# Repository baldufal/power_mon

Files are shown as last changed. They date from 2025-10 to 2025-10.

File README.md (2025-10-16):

# PowerMon
A **9-channel power monitoring and control board** based on the [INA3221](https://www.ti.com/product/INA3221) current sensor and an [ESP32-C3 super mini](https://www.espboards.dev/esp32/esp32-c3-super-mini/) running (a custom compiled version of) [Tasmota](https://tasmota.github.io/).

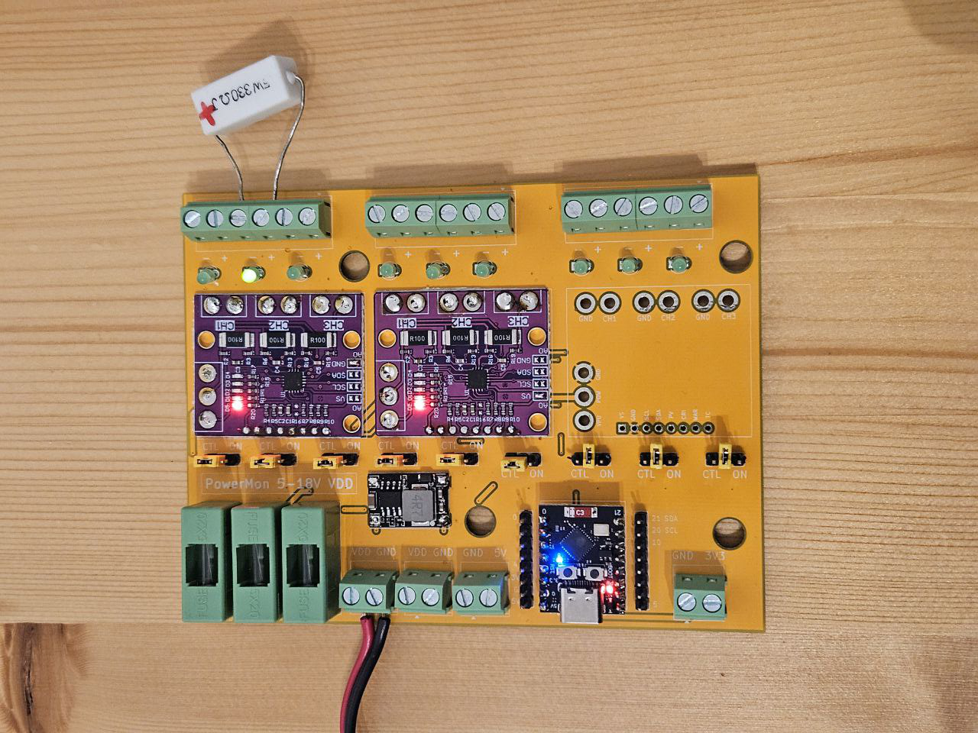
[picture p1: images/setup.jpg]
assembled board

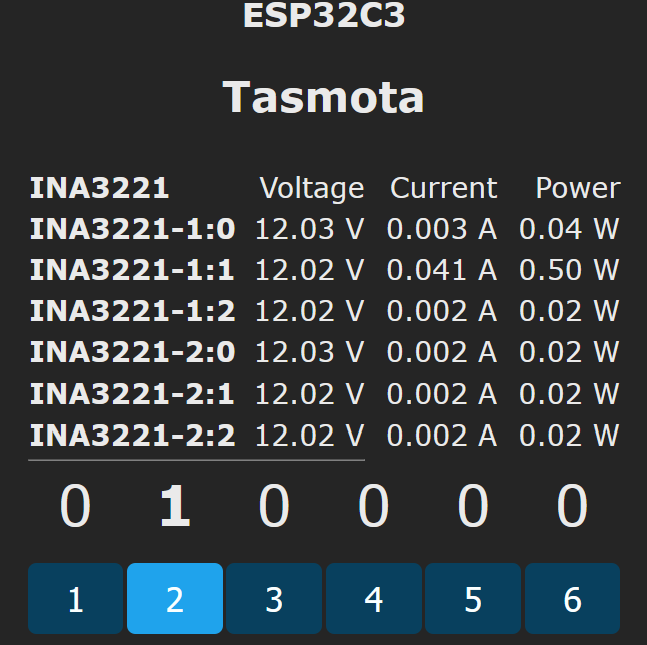
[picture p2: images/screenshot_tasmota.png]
tasmota ui


## Features
- 9 individually controllable output channels
- Each channel can be permanently enabled/disabled using jumpers
- LEDs indicating the output state of each channel
- Power sensing for each individual channel
- -5 ~ 28V output voltage (shared between all outputs)
- 3 integrated fuse holders (5x20mm)

## Board
The board was designed using KiCad 9.
It uses custom symbols and footprints which can be found in the [footprints](footprints) directory.

Care should be taken that the right versions of the ESP32-C3 Super Mini and the INA3221 are selected (see below).
The voltage is regulated using a compact 5V volatage regulator module.

[Schematics](images/schematics_overview.png)
[Schematics for outputs](images/schematics_outputs.png)
[PCB](images/pcb.png)

The board was fabricated by [JLCPCB](https://jlcpcb.com/) and soldered by hand.

### BOM
| Qty | Part |
| --- | --- |
| 1 | **ESP32-C3 Super Mini** (there are [two versions](https://roryhay.es/blog/esp32-c3-super-mini-flaw)) |
| 3 | **INA3221 module** (the [_old version_](https://youtu.be/tCXCQwTQt9Q?si=c6mN08hn90Hn1HyM) with shared GND) |
| 1 | 5V voltage regulator [module](https://de.aliexpress.com/item/1005008257960729.html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) |
| 3 | 5x20mm fuse holder |
| 9 | SOT23 n-Channel FET like [SI2302](https://www.vishay.com/docs/68645/si2302cds.pdf) / A2SHB |
| 9 | 3mm LED with resistors |
| 9 | pin header with 3 poles + jumpers |
| 2 | pin header with 8 poles |
| 13 | 5.08mm terminal blocks with 2 poles |

## Tasmota compilation
As INA3221 support is not enabled in any of the precompiled Tasmota versions, a [custom compiled](https://github.com/tasmota/docs/blob/master/docs/Compile-your-build.md) Tasmota is used.

1. Download the latest version of [Tasmota](https://github.com/arendst/Tasmota) and open it in [PlatformIO](https://platformio.org/).
2. Enable I2C and INA3221 drivers in **tasmota/user_config_override.h** by inserting
```
#ifndef USE_I2C
#define USE_I2C
#endif

#ifndef USE_INA3221
#define USE_INA3221
#endif
```
3. In **platformio_override.ini** change _default_envs_ to `tasmota32c3` and _board_ to `esp32c3`.
4. Compile and upload.

## Tasmota configuration
To configure the freshly flashed Tasmota:

First, [connect it to your wifi](https://tasmota.github.io/docs/Getting-Started/#__tabbed_2_2).

Then, set a **static IP** using the console for a more stable connection ([see the docs](https://tasmota.github.io/docs/Commands/#wi-fi)):
```
ipaddress1 <host IP address>
ipaddress2 <gateway IP address>
ipaddress3 <subnet mask>
ipaddress4 <DNS 1 IP>
ipaddress5 1.1.1.1
```

Then **disable the feature that resets everything** if a `Button` is pressed for 5 seconds:
```
SetOption1 1
```

Then set the **pin configuration**:

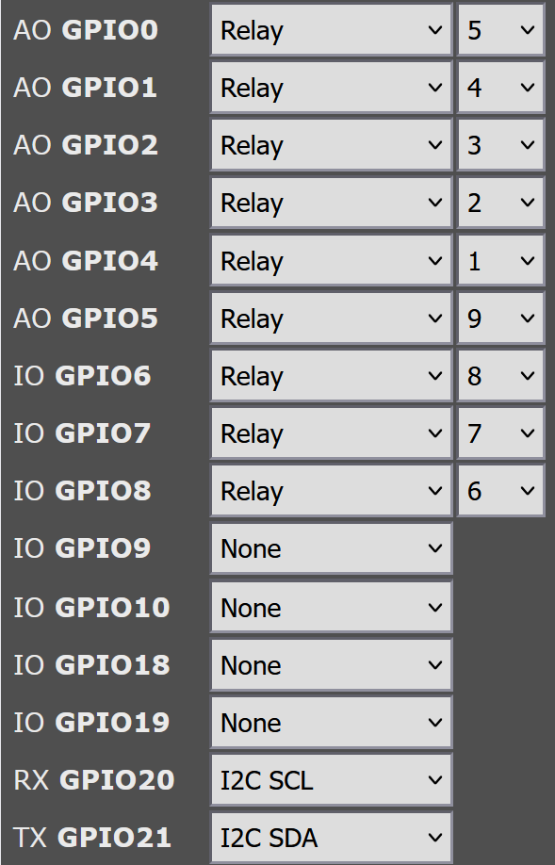
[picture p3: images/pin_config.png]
target pin config


Then create a [rule](https://tasmota.github.io/docs/Rules/) that [**configures the INA3221 sensors**](https://staars.github.io/docs/Commands/#sensors) after startup:
```
Rule1 ON System#Boot DO Sensor100 1, 0.1, 0.1, 0.1 ENDON ON System#Boot DO Sensor100 2, 0.1, 0.1, 0.1 ENDON ON System#Boot DO Sensor100 3, 0.1, 0.1, 0.1 ENDON
```
and enable it:
```
Rule1 1
```

Optionally, configure the number of decimals using
```
VoltRes 2
AmpRes 3
WattRes 2
```

## See also
[Here](https://github.com/arendst/Tasmota/discussions/16660) is a discussion of INA3221 configuration in Tasmota.

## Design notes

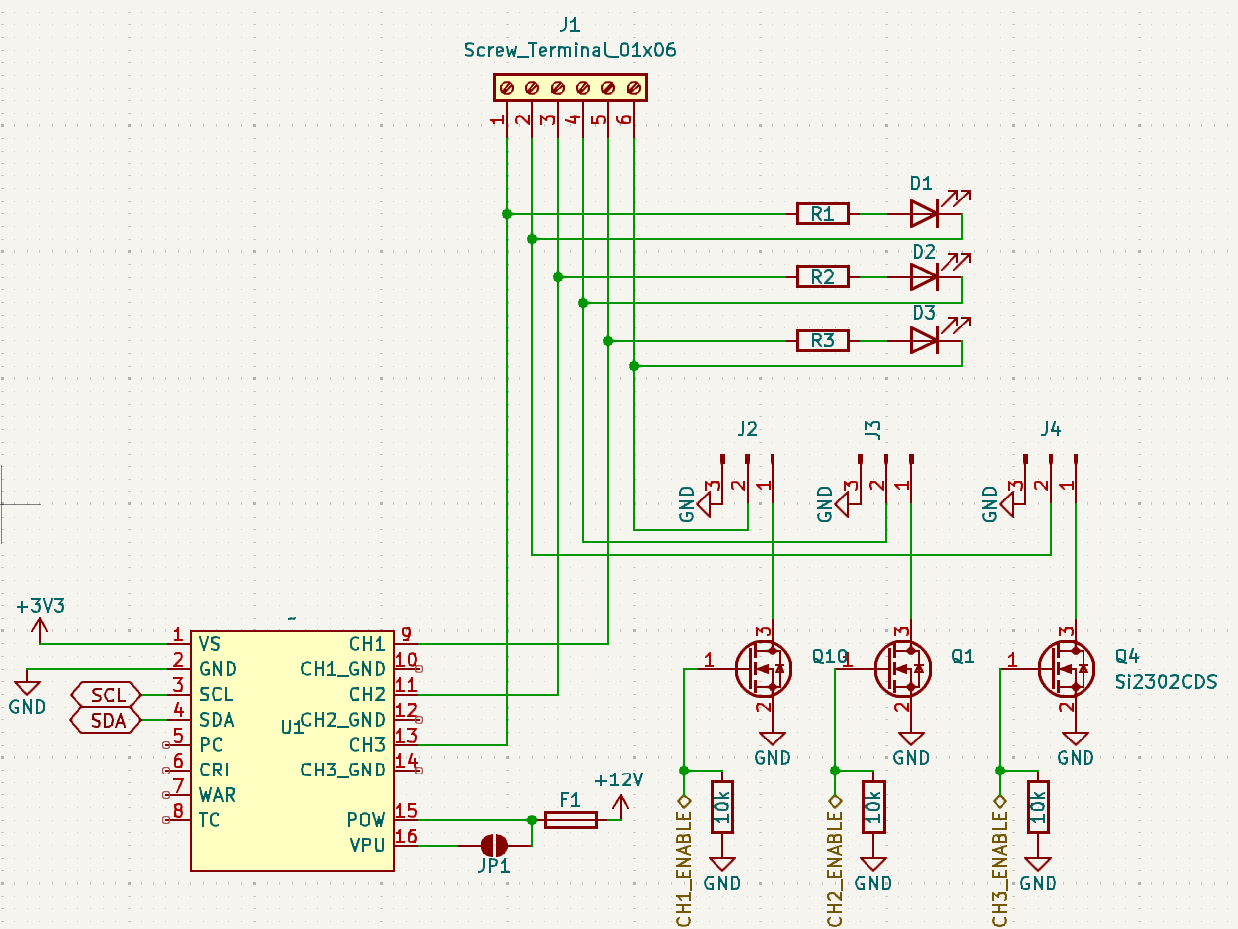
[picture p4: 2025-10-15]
images/schematics_outputs.png

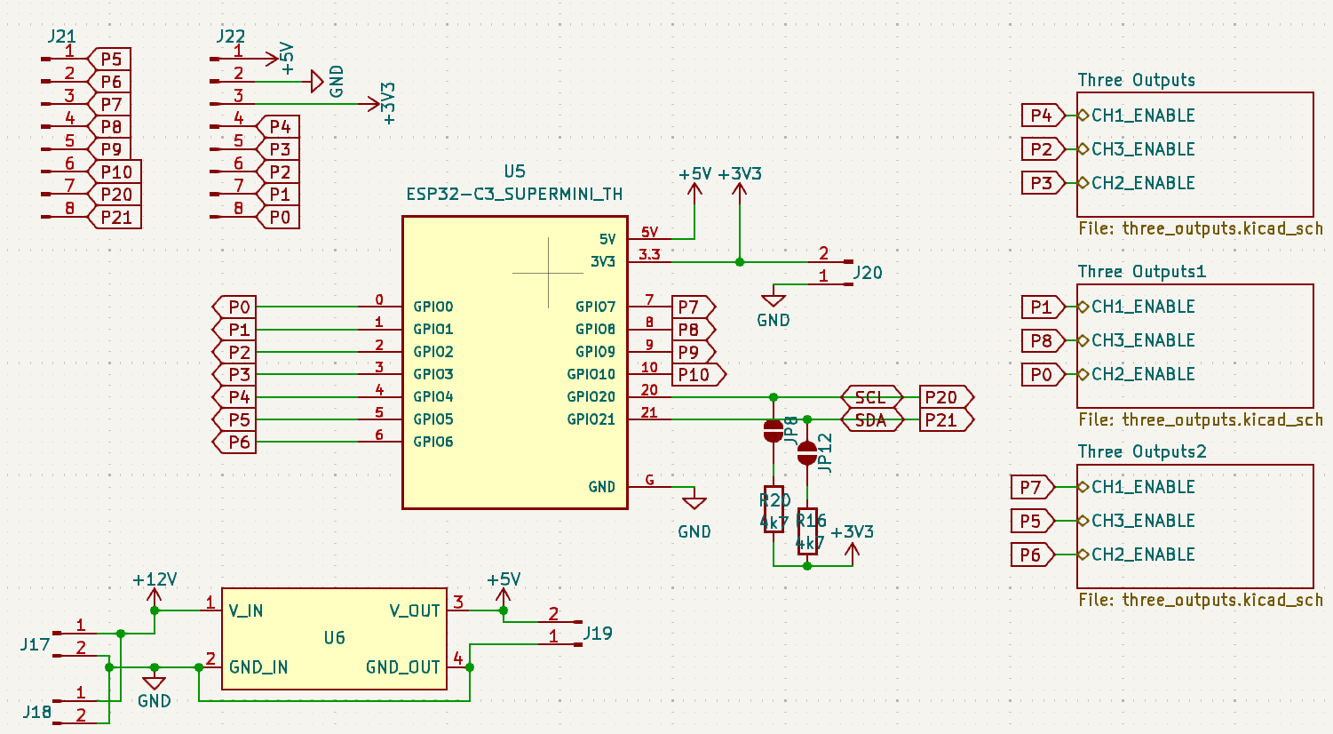
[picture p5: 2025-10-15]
images/schematics_overview.png

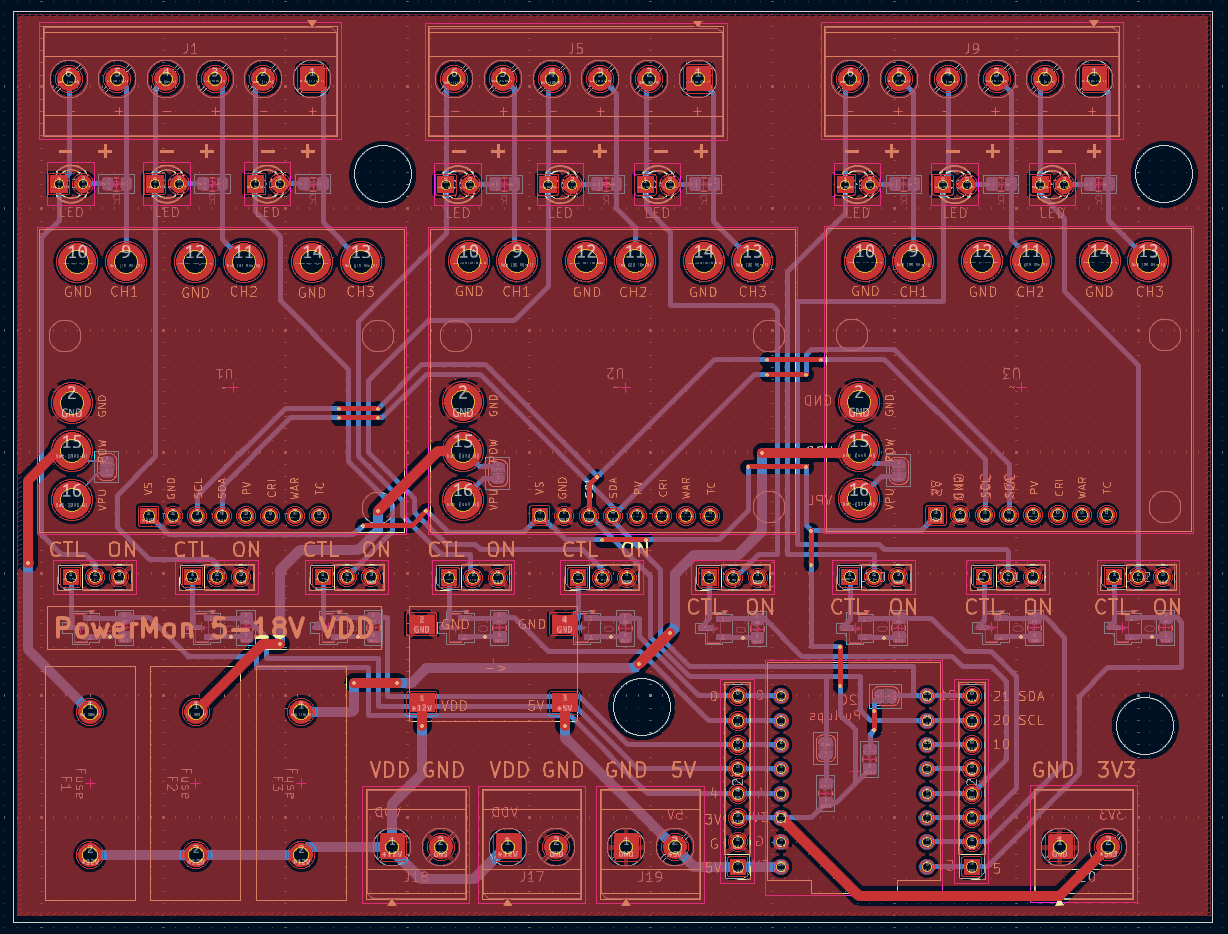
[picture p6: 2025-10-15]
images/pcb.png

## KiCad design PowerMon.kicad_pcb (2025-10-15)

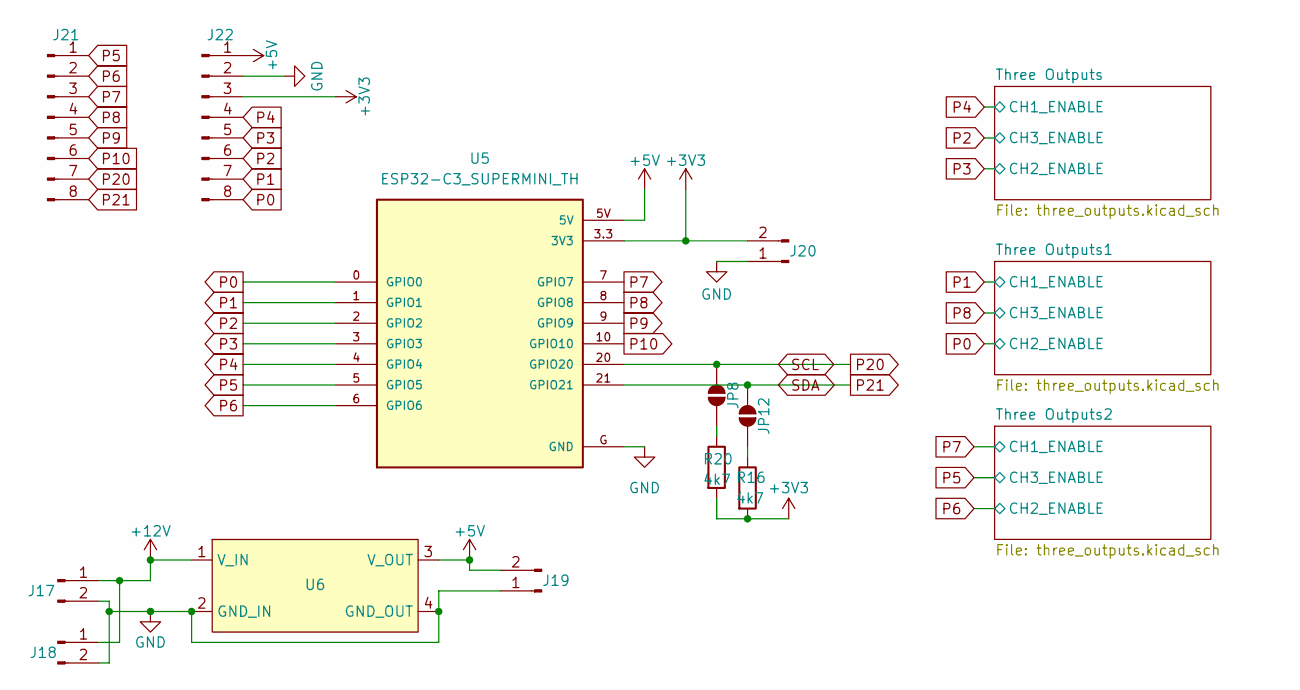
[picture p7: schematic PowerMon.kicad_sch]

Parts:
J17, J18, J19, J20: Conn_01x02_Pin; TerminalBlock_Phoenix_MKDS-3-2-5.08_1x02_P5.08mm_Horizontal
J21, J22: Conn_01x08_Pin; PinHeader_1x08_P2.54mm_Vertical
JP8, JP12: SolderJumper_2_Open; SolderJumper-2_P1.3mm_Open_RoundedPad1.0x1.5mm
R16, R20: 4k7; R_0805_2012Metric_Pad1.20x1.40mm_HandSolder
U5: ESP32-C3_SUPERMINI_TH; MODULE_ESP32-C3_SUPERMINI_TH
U6: DC_DC_3A_Mini_Aliexpress

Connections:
+3V3: J20.2, J22.3, R16.2, R20.2, U5.3.3 (3V3); also elsewhere on the board
+5V: J19.2, J22.1, U5.5V, U6.3 (V_OUT)
+12V: J17.1, J18.1, U6.1 (V_IN); also elsewhere on the board
GND: J17.2, J18.2, J19.1, J20.1, J22.2, U5.G (GND), U6.2 (GND_IN), U6.4 (GND_OUT); also elsewhere on the board
unnamed: JP8.1 (A), R20.1
unnamed: JP12.1 (A), R16.1
P0: J22.8, U5.0 (GPIO0); also elsewhere on the board
P1: J22.7, U5.1 (GPIO1); also elsewhere on the board
P2: J22.6, U5.2 (GPIO2); also elsewhere on the board
P3: J22.5, U5.3 (GPIO3); also elsewhere on the board
P4: J22.4, U5.4 (GPIO4); also elsewhere on the board
P5: J21.1, U5.5 (GPIO5); also elsewhere on the board
P6: J21.2, U5.6 (GPIO6); also elsewhere on the board
P7: J21.3, U5.7 (GPIO7); also elsewhere on the board
P8: J21.4, U5.8 (GPIO8); also elsewhere on the board
P9: J21.5, U5.9 (GPIO9)
P10: J21.6, U5.10 (GPIO10)
P20: J21.7, JP8.2 (B), U5.20 (GPIO20); also elsewhere on the board
P21: J21.8, JP12.2 (B), U5.21 (GPIO21); also elsewhere on the board

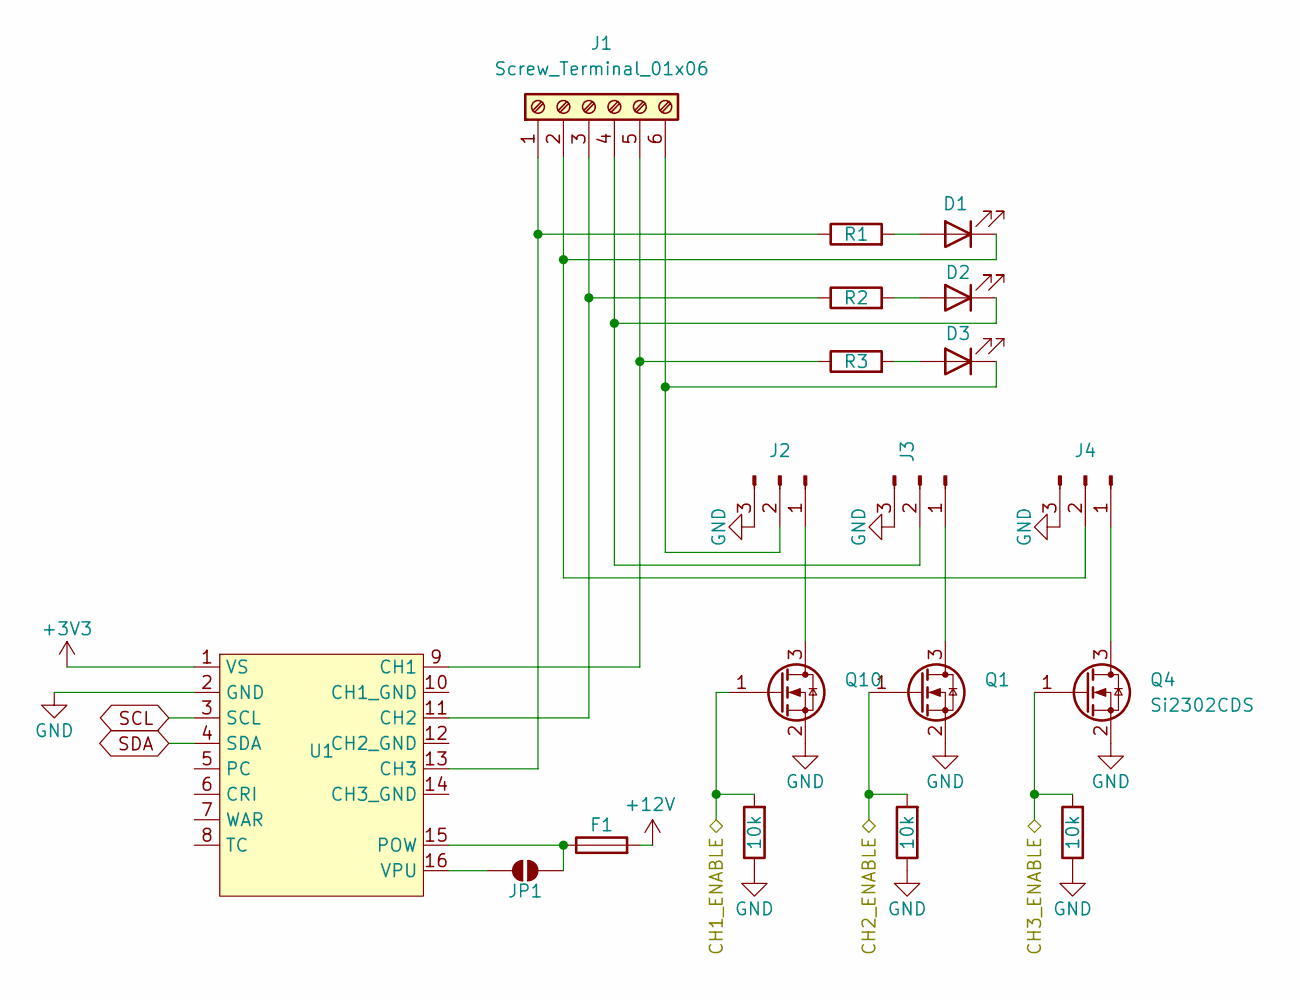
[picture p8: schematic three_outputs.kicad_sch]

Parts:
D1, D2, D3: LED; LED_D3.0mm
F1: Fuse; Fuse Holder 15mm pin distance 5x20
J1: Screw_Terminal_01x06; TerminalBlock_Phoenix_MKDS-3-6-5.08_1x06_P5.08mm_Horizontal
J2, J3, J4: Conn_01x03_Pin; PinHeader_1x03_P2.54mm_Vertical
JP1: SolderJumper_2_Open; SolderJumper-2_P1.3mm_Open_RoundedPad1.0x1.5mm
Q1, Q4, Q10: Si2302CDS; SOT-23
R1, R2, R3: R; R_0805_2012Metric_Pad1.20x1.40mm_HandSolder
R13, R18, R23: 10k; R_0805_2012Metric_Pad1.20x1.40mm_HandSolder
U1: INA3221_Module

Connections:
+3V3: U1.1 (VS); also elsewhere on the board
+12V: F1.2; also elsewhere on the board
GND: J2.3, J3.3, J4.3, Q1.2 (S), Q4.2 (S), Q10.2 (S), R13.1, R18.1, R23.1, U1.2 (GND); also elsewhere on the board
unnamed: D1.2 (A), R1.2
unnamed: D1.1 (K), J1.2, J4.2
unnamed: D2.2 (A), R2.2
unnamed: D2.1 (K), J1.4, J3.2
unnamed: D3.2 (A), R3.2
unnamed: D3.1 (K), J1.6, J2.2
unnamed: J1.1, R1.1, U1.13 (CH3)
unnamed: J1.3, R2.1, U1.11 (CH2)
unnamed: J1.5, R3.1, U1.9 (CH1)
unnamed: J2.1, Q10.3 (D)
unnamed: J3.1, Q1.3 (D)
unnamed: J4.1, Q4.3 (D)
unnamed: JP1.1 (A), U1.16 (VPU)
unnamed: F1.1, JP1.2 (B), U1.15 (POW)
P2: Q4.1 (G), R23.2; also elsewhere on the board
P3: Q1.1 (G), R18.2; also elsewhere on the board
P4: Q10.1 (G), R13.2; also elsewhere on the board
P20: U1.3 (SCL); also elsewhere on the board
P21: U1.4 (SDA); also elsewhere on the board

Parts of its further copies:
D4, D5, D6, D7, D8, D9: LED; LED_D3.0mm
F2, F3: Fuse; Fuse Holder 15mm pin distance 5x20
J5, J9: Screw_Terminal_01x06; TerminalBlock_Phoenix_MKDS-3-6-5.08_1x06_P5.08mm_Horizontal
J6, J7, J8, J10, J11, J12: Conn_01x03_Pin; PinHeader_1x03_P2.54mm_Vertical
JP2, JP3: SolderJumper_2_Open; SolderJumper-2_P1.3mm_Open_RoundedPad1.0x1.5mm
Q2, Q3, Q5, Q6, Q11, Q12: Si2302CDS; SOT-23
R4, R5, R6, R7, R8, R9: R; R_0805_2012Metric_Pad1.20x1.40mm_HandSolder
R14, R15, R19, R21, R24, R25: 10k; R_0805_2012Metric_Pad1.20x1.40mm_HandSolder
U2, U3: INA3221_Module

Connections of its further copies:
+3V3: U2.1 (VS), U3.1 (VS); also elsewhere on the board
+12V: F2.2, F3.2; also elsewhere on the board
GND: J6.3, J7.3, J8.3, J10.3, J11.3, J12.3, Q2.2 (S), Q3.2 (S), Q5.2 (S), Q6.2 (S), Q11.2 (S), Q12.2 (S), R14.1, R15.1, R19.1, R21.1, R24.1, R25.1, U2.2 (GND), U3.2 (GND); also elsewhere on the board
unnamed: D4.2 (A), R4.2
unnamed: D4.1 (K), J5.2, J8.2
unnamed: D5.2 (A), R5.2
unnamed: D5.1 (K), J5.4, J7.2
unnamed: D6.2 (A), R6.2
unnamed: D6.1 (K), J5.6, J6.2
unnamed: D7.2 (A), R7.2
unnamed: D7.1 (K), J9.2, J12.2
unnamed: D8.2 (A), R8.2
unnamed: D8.1 (K), J9.4, J11.2
unnamed: D9.2 (A), R9.2
unnamed: D9.1 (K), J9.6, J10.2
unnamed: J5.1, R4.1, U2.13 (CH3)
unnamed: J5.3, R5.1, U2.11 (CH2)
unnamed: J5.5, R6.1, U2.9 (CH1)
unnamed: J6.1, Q11.3 (D)
unnamed: J7.1, Q2.3 (D)
unnamed: J8.1, Q5.3 (D)
unnamed: J9.1, R7.1, U3.13 (CH3)
unnamed: J9.3, R8.1, U3.11 (CH2)
unnamed: J9.5, R9.1, U3.9 (CH1)
unnamed: J10.1, Q12.3 (D)
unnamed: J11.1, Q3.3 (D)
unnamed: J12.1, Q6.3 (D)
unnamed: JP2.1 (A), U2.16 (VPU)
unnamed: F2.1, JP2.2 (B), U2.15 (POW)
unnamed: JP3.1 (A), U3.16 (VPU)
unnamed: F3.1, JP3.2 (B), U3.15 (POW)
P0: Q2.1 (G), R19.2; also elsewhere on the board
P1: Q11.1 (G), R14.2; also elsewhere on the board
P5: Q6.1 (G), R25.2; also elsewhere on the board
P6: Q3.1 (G), R21.2; also elsewhere on the board
P7: Q12.1 (G), R15.2; also elsewhere on the board
P8: Q5.1 (G), R24.2; also elsewhere on the board
P20: U2.3 (SCL), U3.3 (SCL); also elsewhere on the board
P21: U2.4 (SDA), U3.4 (SDA); also elsewhere on the board

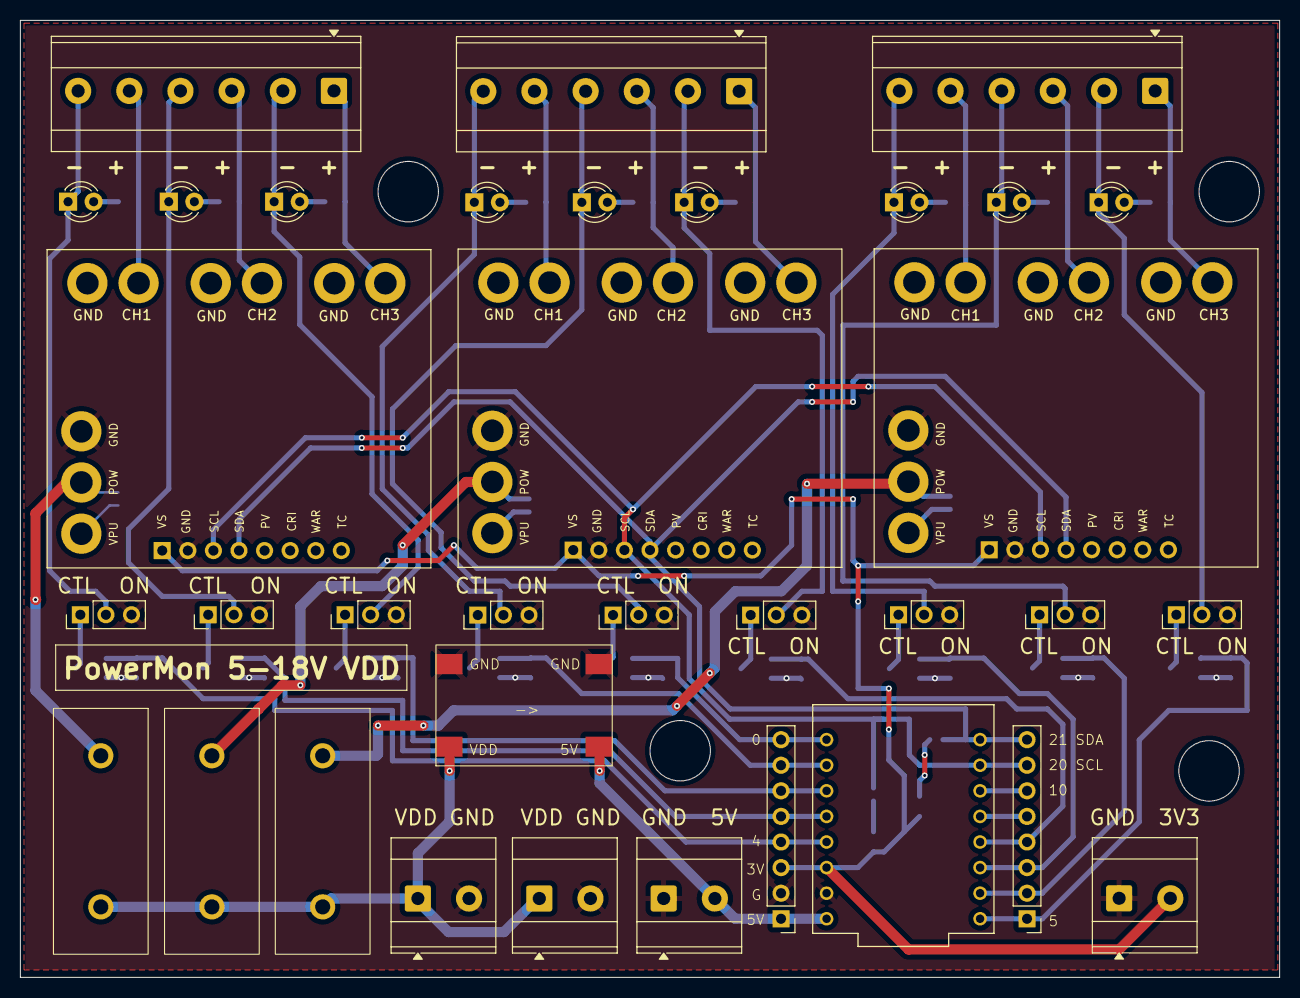
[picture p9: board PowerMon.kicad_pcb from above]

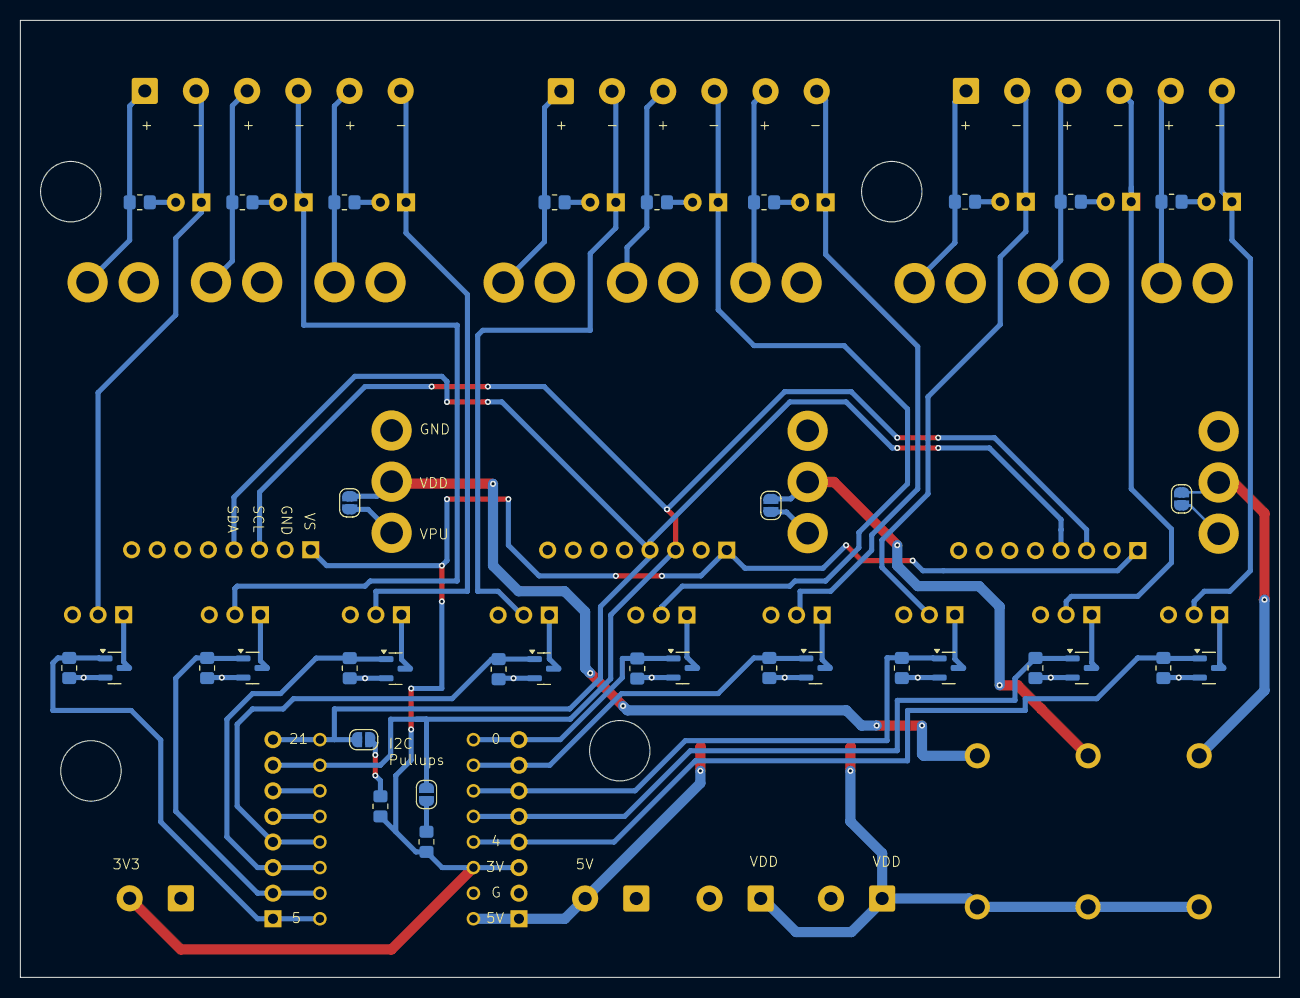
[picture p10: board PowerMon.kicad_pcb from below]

Board: 2 copper layers, 125.0 x 95.0 mm, 69 parts (34 on the bottom side), 61 nets.

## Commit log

2025-10-16 Update README with PowerMon details and instructions
    Added detailed information about the PowerMon board, including features, board design, BOM, and Tasmota compilation instructions.
2025-10-16 Add pin config
